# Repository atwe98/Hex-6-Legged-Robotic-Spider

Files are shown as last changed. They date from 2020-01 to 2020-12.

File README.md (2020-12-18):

# Hex-6-Legged-Robotic-Spider
A bluetooth controlled robot controlled by STM32 (Blue PILL) designed over Solidworks.

Components used:
-Controller: STM32 (Blue Pill),a 32-bit ARM processor chosen for its high processing power, large number of PWM pins and high DAC resolution
-Bluetooth Module: HC-05 
-Servos: SG-90 micro servos
-Power: two 3.7V slim Li-ion connected in series to a buck converter LM2596
-Custom-made shield for easy connection to all components

All custom parts are designed on SolidWorks and converted to DWG for laser cutting.

Project made by Fouad Atwi and Buraq Al Alaeli
Presented as a project for Electric Machines I

(Photos and circuit schematics to be uploaded later)

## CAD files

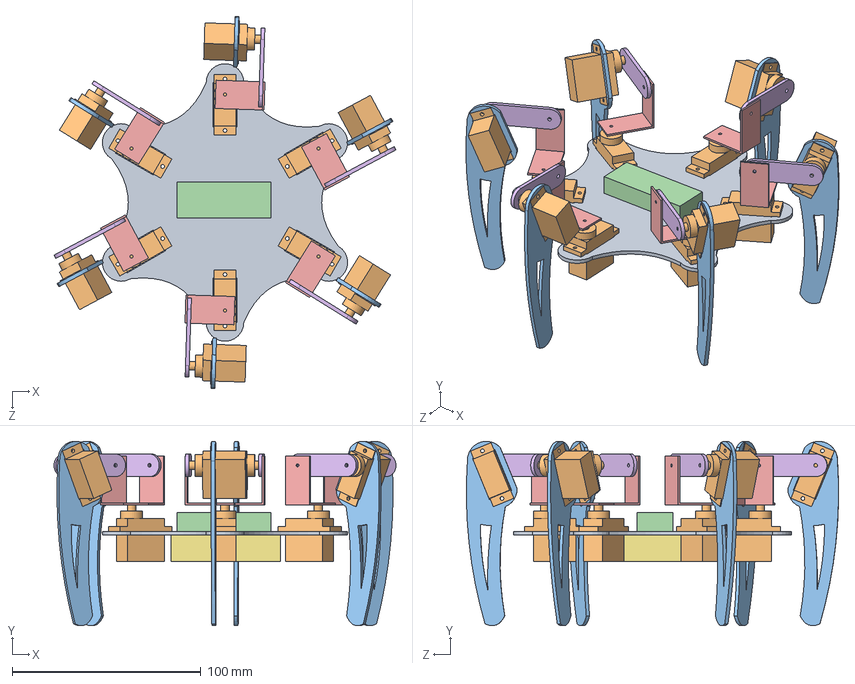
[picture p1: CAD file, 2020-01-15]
Chassis Design/SolidWorks/Assembly/Assem2.SLDASM
181.4 x 97.8 x 197.4 mm
MainChasis
SG90 x 12
FeetExternal x 6
BluePill
90degreejoint x 6
FeetInternal x 6
AA battery holder

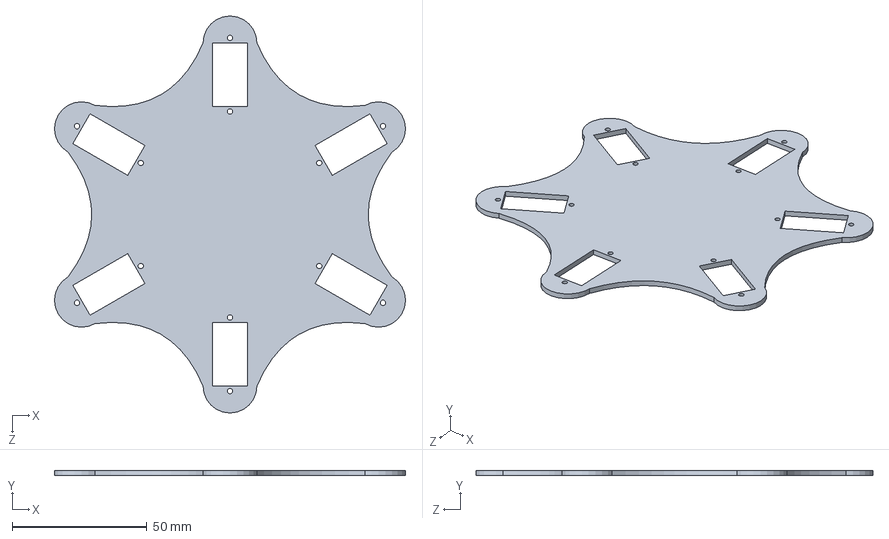
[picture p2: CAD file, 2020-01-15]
Chassis Design/SolidWorks/MainChasis.SLDPRT
130.2 x 2.00 x 147.2 mm

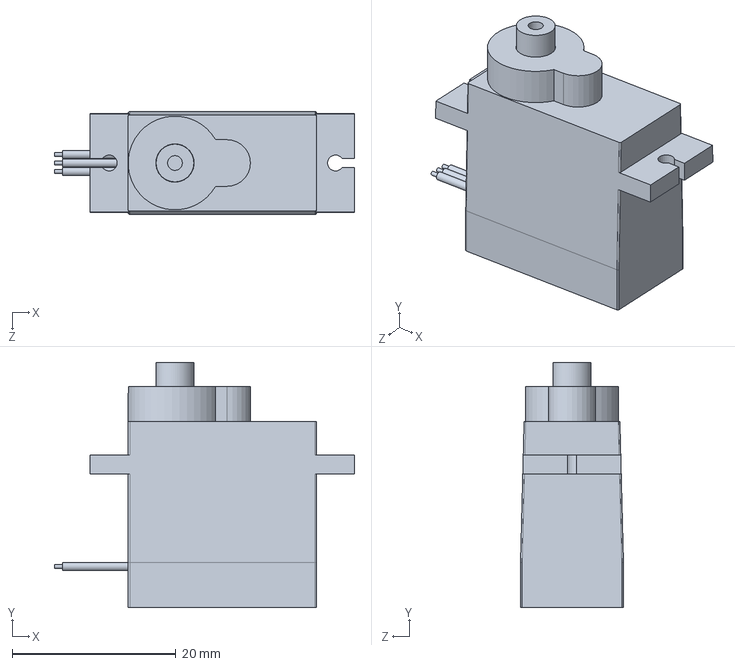
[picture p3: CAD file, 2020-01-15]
Chassis Design/SolidWorks/User Library-Tower Pro 9g Micro Servo SG90.SLDPRT
36.7 x 30.0 x 12.6 mm

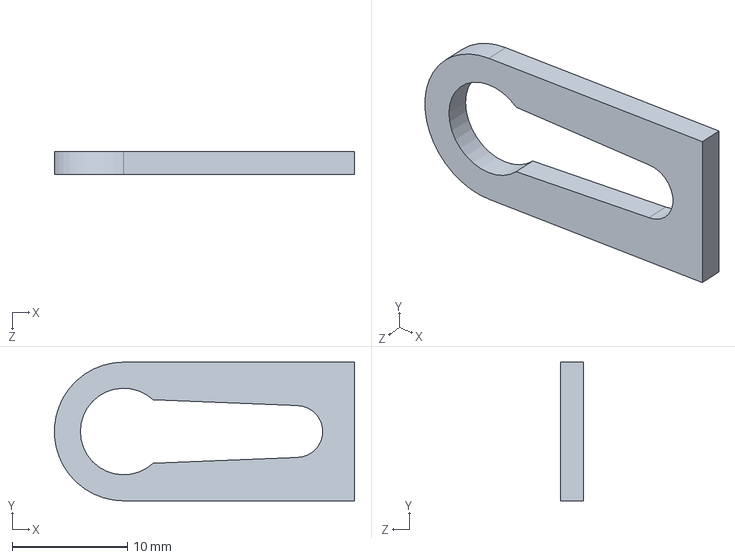
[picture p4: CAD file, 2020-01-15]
Chassis Design/SolidWorks/FeetInternal2.SLDPRT
26.0 x 12.0 x 2.00 mm

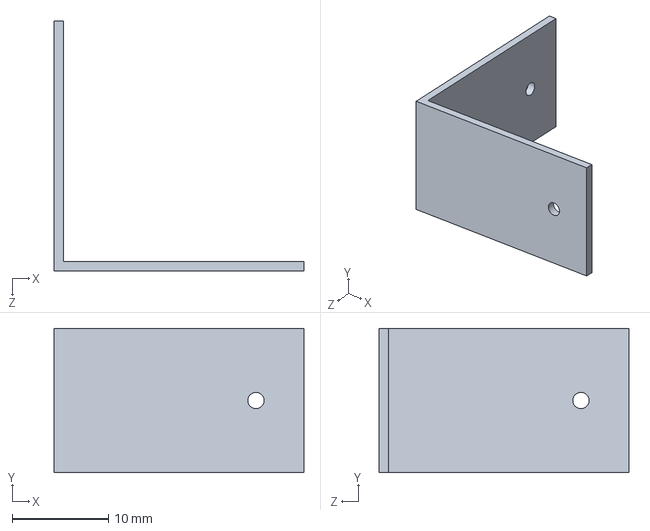
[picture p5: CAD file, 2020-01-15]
Chassis Design/SolidWorks/90degreejoint.SLDPRT
26.0 x 15.0 x 26.0 mm

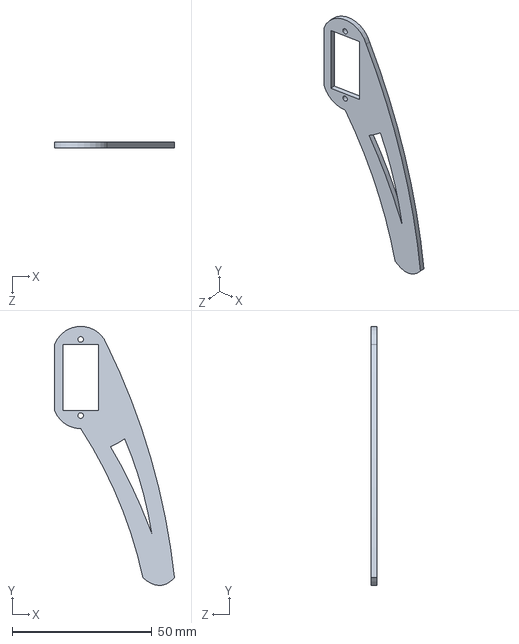
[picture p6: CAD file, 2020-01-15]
Chassis Design/SolidWorks/FeetExternal.SLDPRT
43.0 x 92.8 x 2.00 mm

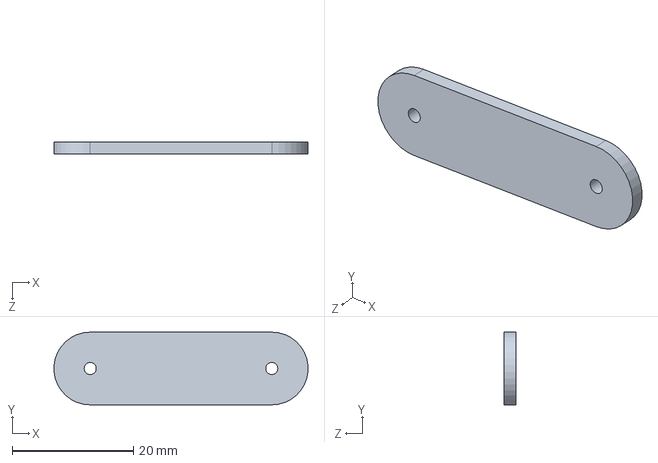
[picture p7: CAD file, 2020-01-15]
Chassis Design/SolidWorks/FeetInternal.SLDPRT
42.0 x 12.0 x 2.00 mm

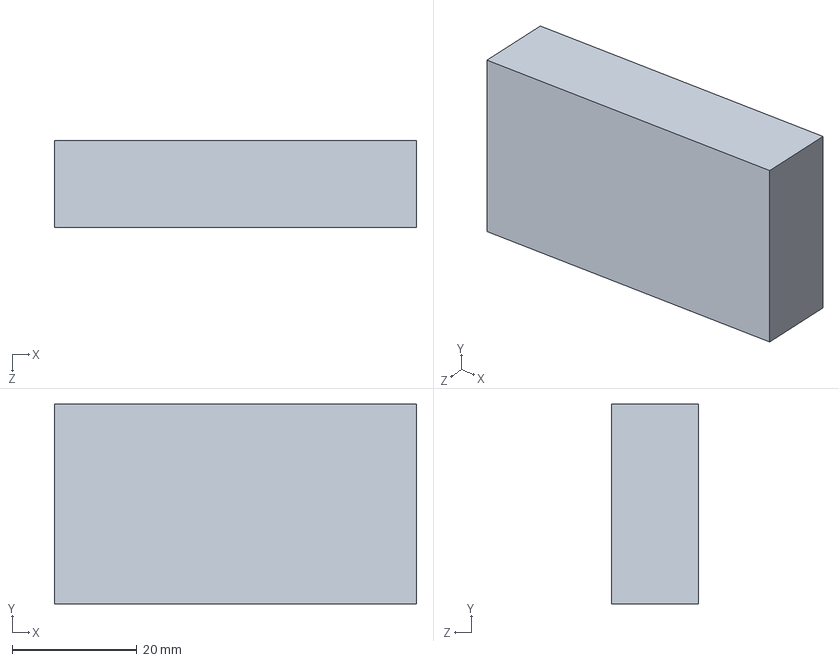
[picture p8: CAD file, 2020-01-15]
Chassis Design/SolidWorks/AA battery holder.SLDPRT
58.0 x 32.0 x 14.0 mm

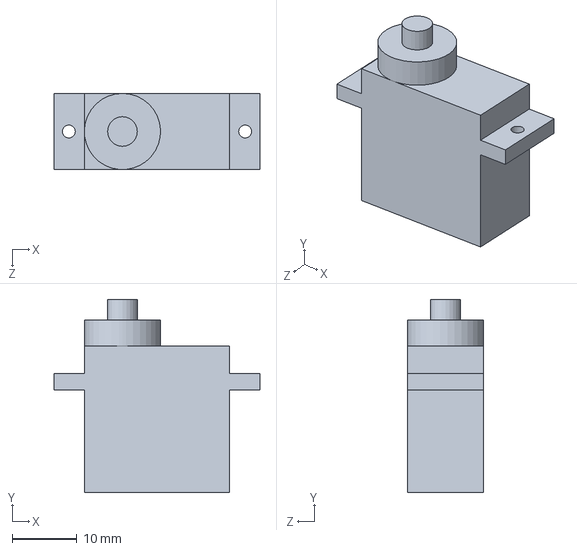
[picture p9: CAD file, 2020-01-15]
Chassis Design/SolidWorks/SG90.SLDPRT
31.9 x 29.9 x 11.8 mm

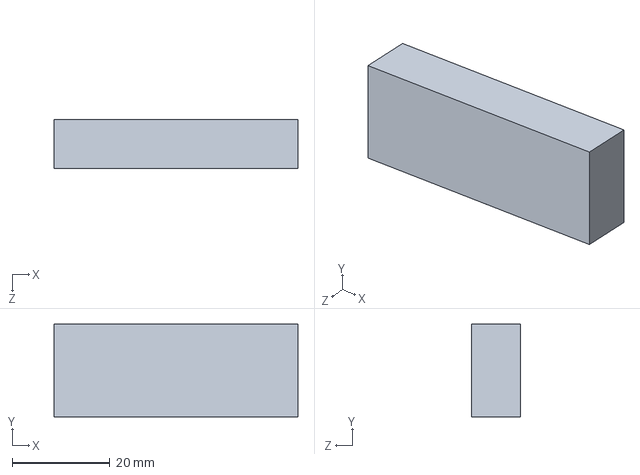
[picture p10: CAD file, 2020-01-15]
Chassis Design/SolidWorks/BluePill.SLDPRT
50.0 x 19.0 x 10.0 mm

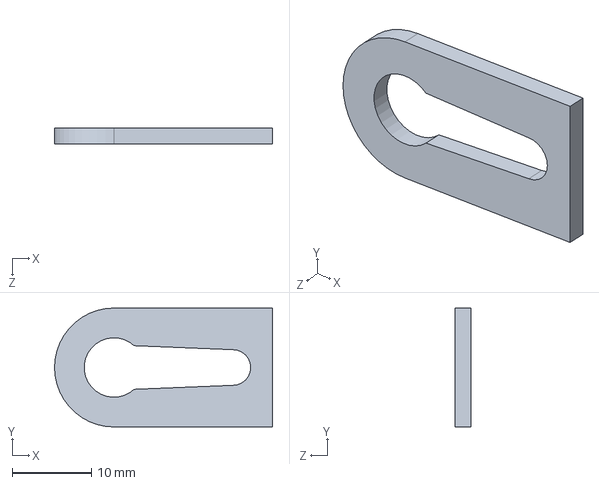
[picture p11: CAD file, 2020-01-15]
Chassis Design/SolidWorks/FeetInternal3.SLDPRT
27.5 x 15.0 x 2.00 mm

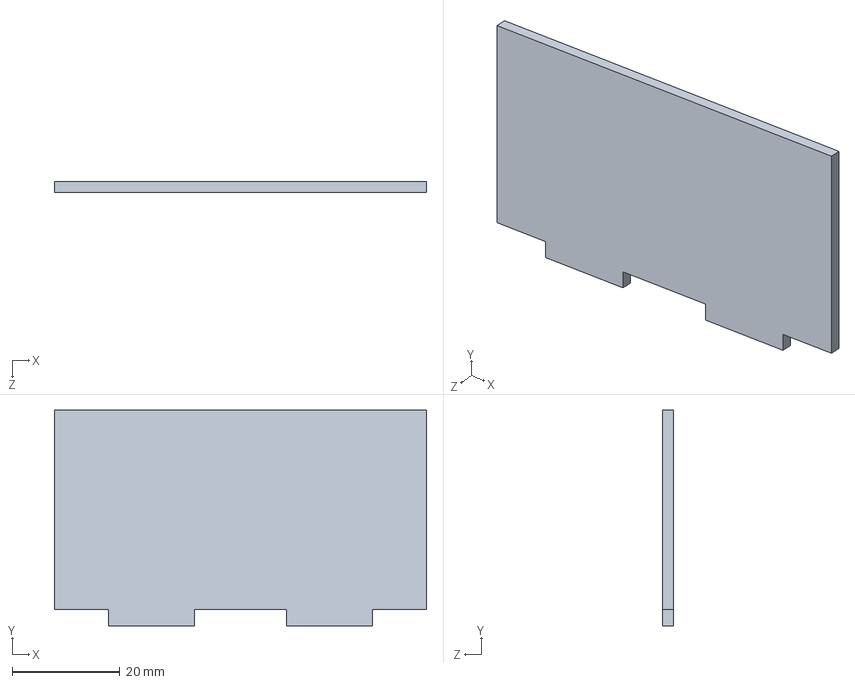
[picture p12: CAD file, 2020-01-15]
Chassis Design/SolidWorks/Wall1.SLDPRT
69.0 x 40.0 x 2.00 mm

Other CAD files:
Chassis Design/AutoCAD/MainChasis.DWG
Chassis Design/AutoCAD/MainChasis-Edited.DWG
Chassis Design/AutoCAD/FeetInternal2.DWG
Chassis Design/AutoCAD/FeetInternal.DWG
Chassis Design/AutoCAD/FeetInternal3.DWG
Chassis Design/AutoCAD/FeetExternal.DWG

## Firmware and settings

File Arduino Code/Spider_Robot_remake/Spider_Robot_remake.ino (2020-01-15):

#include <Servo.h>
class servo{
  public: 
  int mi,ma,cur,dif,len;
  Servo s;
  servo(int PIN,int MIN,int MAX){
    s.attach(PIN);
    mi=MIN;
    ma=MAX;
    dif=ma-mi;
  }
  servo(){
    mi =0;
    ma =0;
    dif = 0;
  }
  void Write(int pos){
      s.write(pos);
  }
  void Write(char c){
    if(c=='h')
      s.write(ma);
    else if(c=='l')
      s.write(mi);
  }
};
int cases;
int CA[1000];
int b[]={PA8,PA3,PA6,PA7,PB0,PB1}; 
int e[]={PB6,PB7,PB8,PA2,PA1,PA0};
int inMin[6]={25,48,115,65,115,25};
int inMax[6]={60,113,150,30,50,60};
int outMin[6]={120,132,65,105,65,55};
int outMax[6]={145,157,40,130,40,30 };
int m = PA1;
servo SI[6];
servo SO[6];
int trigPin1 = 9, echoPin1 = 10,trigPin2 = 11, echoPin2 = 12;
long duration1,duration2;
int distance1,distance2;
int speedValue = 10;
int d;
int threshold;
int radarAngle = 90;
int dir;

//--------------------------------------------
void trans(servo a[],char c,int STEP,int siz){
  for(int i=1;i<=STEP;i++){
    for(int j=0;j<siz;j++){
      if(c=='f')
        a[j].Write(a[j].mi+a[j].dif/STEP*i);
      else if(c=='b')
        a[j].Write(a[j].ma-a[j].dif/STEP*i);
    }
    delay(speedValue);
  }
}
void transR(servo a[],int STEP){
  for(int i=1;i<=STEP;i++){
    for(int j=0;j<3;j++){
        a[j].Write(a[j].mi+a[j].dif/STEP*i);
        a[j+3].Write(a[j+3].ma-a[j+3].dif/STEP*i);
    }
    delay(10);
  }
}
void transL(servo a[],int STEP){
  for(int i=1;i<=STEP;i++){
    for(int j=0;j<3;j++){
        a[j].Write(a[j].ma-a[j].dif/STEP*i);
        a[j+3].Write(a[j+3].mi+a[j+3].dif/STEP*i);
    }
    delay(10);
  }
}
void initialStand(){
  for(int i=0;i< 6; i++){
    SI[i].Write((SI[i].mi+SI[i].ma)/2);
    SO[i].Write(SO[i].mi);
  }
  delay(200);
}
void Die(){
  for(int i=0;i< 6; i++){
    SI[i].Write((SI[i].mi+SI[i].ma)/2);
    SO[i].Write(SO[i].ma);
  }
}
void forward(){
  for(int i=0;i<6;i+=2)
    SO[i].Write('h');
  delay(10);
  SI[0].Write('h');
  SI[2].Write('h');
  SI[4].Write('h');
  delay(50);
  for(int i=0;i<6;i+=2)
    SO[i].Write('l');
  delay(10);
  for(int i=1;i<6;i+=2)
    SO[i].Write('h');
  delay(10);
  servo a[]={SI[0],SI[2],SI[4]};
  trans(a,'b',25,3);
  for(int i=1;i<6;i+=2) 
    SO[i].Write('l');
  //-----------------------------------
  for(int i=1;i<6;i+=2)
    SO[i].Write('h');
  delay(10);
  SI[1].Write('h');
  SI[3].Write('h');
  SI[5].Write('h');
  delay(50);
  for(int i=1;i<6;i+=2)
    SO[i].Write('l');
  delay(10);
  for(int i=0;i<6;i+=2)
    SO[i].Write('h');
  delay(10);
  servo q[]={SI[1],SI[3],SI[5]};
  trans(q,'b',25,3);  
  for(int i=0;i<6;i+=2) 
    SO[i].Write('l');
  delay(20);
}                                                     
void rotate(bool b){
  for(int i=0;i<6;i+=2)
    SO[i].Write('h');
  delay(50);
  SI[0].Write('h');
  SI[2].Write('h');
  SI[4].Write('l');
  delay(50);
  for(int i=0;i<6;i+=2)
    SO[i].Write('l');
  delay(100);
  for(int i=1;i<6;i+=2)
    SO[i].Write('h');
  delay(100);
  SI[1].Write('h');
  SI[3].Write('l');
  SI[5].Write('l');
  delay(100);
  for(int i=1;i<6;i+=2)
    SO[i].Write('l');
  servo z[] = {SI[0],SI[1],SI[2],SI[3],SI[4],SI[5]};
  transR(z,25);

  delay(10);
}
void rotateR(bool b){
  for(int i=0;i<6;i+=2)
    SO[i].Write('h');
  delay(50);
  SI[0].Write('l');
  SI[2].Write('l');
  SI[4].Write('h');
  delay(50);
  for(int i=0;i<6;i+=2)
    SO[i].Write('l');
  delay(100);
  for(int i=1;i<6;i+=2)
    SO[i].Write('h');
  delay(100);
  SI[1].Write('l');
  SI[3].Write('h');
  SI[5].Write('h');
  delay(100);
  for(int i=1;i<6;i+=2)
    SO[i].Write('l');
  servo z[] = {SI[0],SI[1],SI[2],SI[3],SI[4],SI[5]};
  transL(z,25);

  delay(10);
}
void Hello()
{
  SI[0].Write(110);
  SO[0].Write(180);
  delay(100);
  for(int i = 0;i<5;i++){
    SI[0].Write(140);
    delay(100);
    SI[0].Write(110);
    delay(100);
  }
  initialStand();
}
void setup(){
  Serial3.begin(9600);
  Serial.begin(9600);
  for(int i=0;i<6;i++){
    SI[i] = servo(b[i],inMin[i],inMax[i]);
    SO[i] = servo(e[i],outMin[i],outMax[i]);   
  }
  initialStand();
  delay(500);
}
void loop(){
  char c;
  if(Serial3.available()!= 0){
    c = Serial3.read();
    Serial3.flush();
    if(c<'z' && c > 'a')
      Serial.println(c);
  }
  switch(c){
    case 'f':
      forward();
      Serial.println ("moving forward");
      break;
    case 's':
      initialStand();
      Serial.println("standing");
      break;
    case 'r':
      rotate(1);
      Serial.println("rotating");
      break;
    case 't':
      SO[0].Write('h');
      break;
    case 'h':
      Hello();
      break;
    case 'd':
      Die();
      break;
    case 'l':
      rotateR(1);
      break;
    
  }
}

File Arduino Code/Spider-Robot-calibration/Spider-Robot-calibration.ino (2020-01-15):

#include <Servo.h>
int cases;
int CA[1000];
int b[]={PB1,PB0,PA7,PB8,PB7,PB6};
int c[]={PA6,PA3,PA2,PA1,PA0,PA8};
Servo SI[6];
Servo SO[6];
char a;
int d;
int val;
void setup(){
  Serial.begin(9600);
  for(int i=0;i<6;i++){
    SI[i].attach(b[i]);
    SO[i].attach(c[i]);
  }
}
void loop(){
  bla:
  while(!Serial.available());
  a=Serial.read();
  Serial.flush();
  while(!Serial.available());
  d=Serial.parseInt();
  Serial.flush();
  while(!Serial.available());
  val=Serial.parseInt();
  Serial.flush();
  if(val==666666)
    goto bla;
  switch(a){
    case 'b': SI[d].write(val);
      Serial.println("b");
      Serial.println(val);
      break;
    case 'c': SO[d].write(val);
      Serial.println("c");
      Serial.println(val);
      break;
  }
  Serial.println("OKI");
  delay(100);
}

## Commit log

2020-01-15 Add files via upload
    Chassis design on SolidWorks and AutoCAD converted files for laser cutting
    [90degreejoint.SLDPRT, AA battery holder.SLDPRT, Assem2.SLDASM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]
2020-01-15 Add files via upload
    SolidWorks and AutoCAD converted files for laser cutting
    [90degreejoint.SLDPRT, AA battery holder.SLDPRT, Assem2.SLDASM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]
